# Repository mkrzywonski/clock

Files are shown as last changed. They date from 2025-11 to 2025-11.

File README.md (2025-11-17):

# Clock (Raspberry Pi LED Clock)

A Python-powered nightstand clock for Raspberry Pi Zero 2 W with an I²C LED display and a rotary navigation encoder.  
It syncs time via NTP, supports adjustable brightness, and includes an on-device menu to configure Wi-Fi, time format, timezone, and colon flash.

## ✨ Features

- Accurate time from NTP
- 4-digit HT16K33 LED display (14-segment)
- Smooth brightness control using a rotary encoder
- On-device settings menu:
  - Wi-Fi SSID selection + password entry
  - 12/24-hour mode
  - Timezone selection
  - Colon flash toggle
- Auto-start at boot via systemd
- Clean Python structure (Display class, input handlers, state machine)

## 📷 Photos
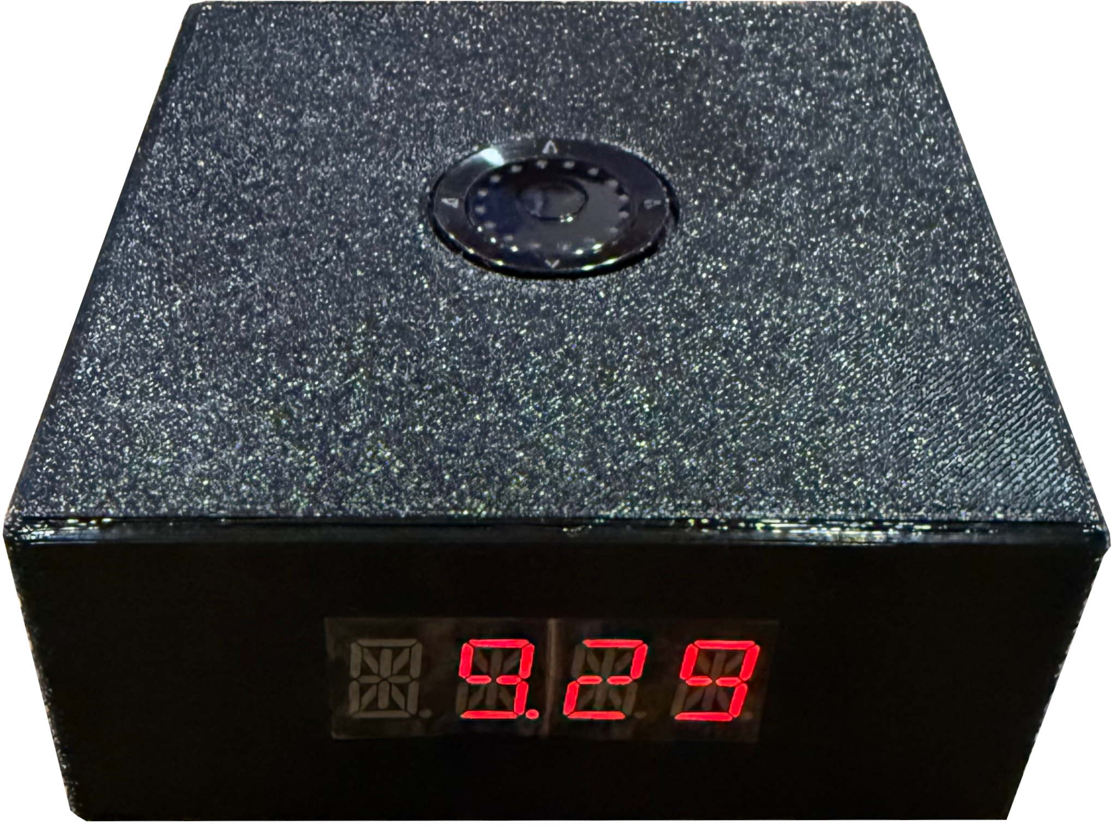
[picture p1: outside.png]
Clock exterior

Clock interior

## 🧰 Hardware

- **Raspberry Pi Zero 2 W** (other Pis likely work)
- **HT16K33 LED display** (I²C; 0x70 default address)
  https://www.amazon.com/dp/B0C1C5W7V6
- **Adafruit ANO Rotary Navigation Encoder Breakout (PID 6311)**  
  – 2 quadrature pins for rotation, 5 momentary buttons, separate commons
  https://www.adafruit.com/product/6311
- **3D Printed Case** https://www.tinkercad.com/things/d59hjFyJgNW-clock

> Power and logic are 3.3 V. Use internal pull-ups on the Pi GPIO and tie the board’s commons to **GND**.

### Example Wiring

| Encoder Pin | Purpose | Pi GPIO (BCM) | Notes |
|---|---|---|---|
| ENCA | Encoder A | GPIO17 | Input w/ internal pull-up |
| ENCB | Encoder B | GPIO18 | Input w/ internal pull-up |
| COMA | Encoder common | GND | Tie to Pi ground |
| SW1 | Button 1 (up) | GPIO27 | Input w/ internal pull-up |
| SW2 | Button 2 (down) | GPIO23 | Input w/ internal pull-up |
| SW3 | Button 3 (left) | GPIO22 | Input w/ internal pull-up |
| SW4 | Button 4 (right) | GPIO24 | Input w/ internal pull-up |
| SW5 | Button 5 (center press) | GPIO4 | Input w/ internal pull-up |
| COMB | Buttons common | GND | Tie to Pi ground |

**I²C display**

| Display Pin | Purpose | Pi Header |
|---|---|---|
| VCC | 3.3 V | 3V3 |
| GND | Ground | GND |
| SDA | I²C data | GPIO2 (SDA) |
| SCL | I²C clock | GPIO3 (SCL) |

## 🖥️ Software Requirements

- Python 3.11+ (Pi OS / Debian Bookworm/Trx)
- `smbus2` (I²C)
- `gpiozero` (inputs)  
  *(or your preferred GPIO library—adjust code accordingly)*

Optional:
- `systemd` (to run at boot)
- `timedatectl` / NTP client (for time sync)

## 🚀 Quick Start

```bash
# 1) Enable I²C (one-time)
# Add this line to /boot/firmware/config.txt and reboot:
#   dtparam=i2c_arm=on
# Then verify:
sudo apt update
sudo apt install -y i2c-tools
i2cdetect -y 1          # should show 0x70 (or your display address)

# 2) Clone the repo (use your own URL)
git clone https://github.com/<your-username>/clock.git
cd clock

# 3) Python venv
python3 -m venv venv
source venv/bin/activate
pip install -U pip
pip install -r requirements.txt  # if present; otherwise:
pip install smbus2 gpiozero

# 4) Run
python clock.py
```

If your display is on a different bus or address, adjust in the code (e.g., `bus=1`, `address=0x70`).

## 🧭 Usage & Controls

- **Default state:** Clock display (updates once per second)
- **Rotate encoder:** Adjust brightness in Clock state
  - Button press (center) → save setting
- **Button press (left/right):** Enter/cycle menu
  - **Wi-Fi SSID** → choose network
    - **Wi-Fi password** → enter using buttons/rotation
  - **12/24-hour** → toggle
  - **Timezone** → choose from curated list
  - **Colon flash** → toggle
  - **Display IP Address**

## 🧷 Systemd (run at boot)

Create `/etc/systemd/system/clock.service`:

```ini
[Unit]
Description=Pi LED Clock
After=network-online.target
Wants=network-online.target

[Service]
Type=simple
User=pi
WorkingDirectory=/home/pi/clock
ExecStart=/home/pi/clock/venv/bin/python /home/pi/clock/clock.py
Restart=on-failure
Environment=PYTHONUNBUFFERED=1

[Install]
WantedBy=multi-user.target
```

Enable it:

```bash
sudo systemctl daemon-reload
sudo systemctl enable --now clock.service
systemctl status clock.service
```

## 📶 Wi-Fi Configuration from the button pad

You probably configured Wi-Fi when you set up your Pi, but the menu can also scan SSIDs and configure credentials on-device without the need to connect a monitor and keyboard. This can be helpful if you move the clock to a location with a different Wi-Fi network.

**Instructions**
- Select WiFi from the menu and press the center button.
- The clock will scan for available networks. Use the up/down buttons to view the available SSIDs. Press the center button to select the desired SSID.
- The clock will prompt you to enter a password.
  - A single 'a' will be displayed by default
  - Use the up/down buttons or the rotary dial to select the character at the first position.
  - Use the left right arrows to change position. (e.g. select the first character of your password, then press the right arrow to move to the second character and repeat)
  - Press the center button to finish editing.
  - The clock will display the password you entered.
  - Press the left/right buttons to continue editing characters, or press the center button to accept.
  - The clock will display "GOOD" if the SSID and password were valid. The credntials will be saved.
  - The clock will display "FAIL" if the SSID and password were not vailid. Try again.
 
**Note:**
Not all typable characters can be unambiguously displayed on a 14 segment LED display. While accepting characters in the password entry routine, all four digits of the display will be used to identify the exact character being entered. The first three leftmost digits are used to indicate upper/lower case, symobols, etc. The rightmost digit will attempt to display the actual character.

For example, 1, l, i, !, |, ;, and : are all displayed the same on the 14-segment display. While entering the Wi-Fi password, '1' will be shown as "N  1" to indicate that it is a (N)umeral 1. 'l' will be displayed as "↓L l" indicating that it is a lower case L. 'i' will be displayed as "↓I i". '!' will be displayed as "↑1 !", indicating the symbol typed by pressing Shift-1 on a keyboard. And '|' will be displayed as "PIP|" indicating a pipe character. Colon and semicolon are displayed as "COL:" and "SCL;" respectively. All these characters look similar on a single 14-segment display digit. Use the 3 leftmost digits to tell these characters apart.

TLDR: The character displayed on the rightmost digit will be the closest possible 14-segment representation of the character you are entering. The Leftmost 3 digits will idicate uper/lower case or other symbols to disambiguate similarly displayed characters.

## 🧯 Troubleshooting

- **Display shows nothing**
  - `i2cdetect -y 1` should show `0x70` (or your address)
  - Check `dtparam=i2c_arm=on` and SDA/SCL wiring
- **Only some segments light**
  - Verify 14-segment mapping and that you’re writing both high/low bytes per digit
- **Encoder not responding**
  - Confirm you wired **COMA/COMB to GND** and enabled internal pull-ups on ENCA/ENCB/SW*
  - Try swapping A/B if direction feels reversed
- **Buttons double-trigger**
  - Add debounce in code (gpiozero has `bounce_time`), ensure solid ground
- **Permissions**
  - User must be in `i2c` and `gpio` groups on some setups:
    ```bash
    sudo adduser $USER i2c
    sudo adduser $USER gpio
    ```
    Log out/in.

## 🧾 License

GNU GENERAL PUBLIC LICENSE (GPLv3)

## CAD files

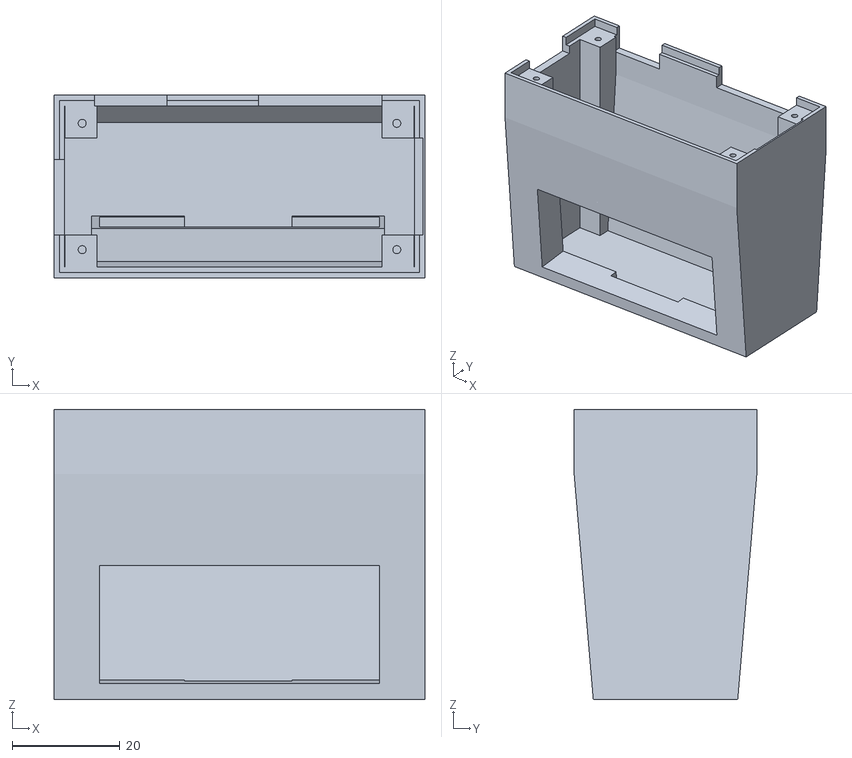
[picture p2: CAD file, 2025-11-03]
small.stl
69.0 x 34.0 x 54.0

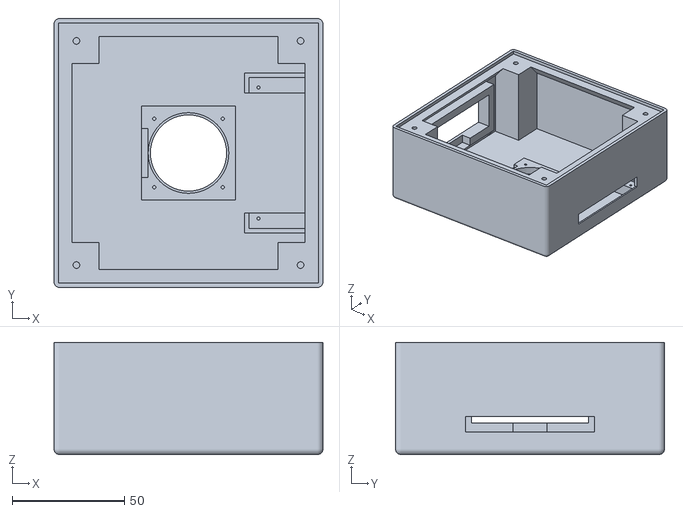
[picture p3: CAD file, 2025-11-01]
clock.stl
120.0 x 120.0 x 50.0

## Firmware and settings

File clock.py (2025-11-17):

from smbus2 import SMBus
import time
from datetime import datetime
import pytz
import sys
import select
import tty
import termios
import threading
import queue
import json
import os
from enum import Enum, auto
import subprocess
import re
from gpiozero import Device, Button, RotaryEncoder
from gpiozero.pins.pigpio import PiGPIOFactory

class ClockSettings:
    def __init__(self, filename="clock_settings.json"):
        self.filename = filename
        self.brightness = 0
        self.timezone = "America/Chicago"
        self.hour_24 = False
        self.flash_colon = True
        self.load()

    def load(self):
        if os.path.exists(self.filename):
            try:
                with open(self.filename, "r") as f:
                    data = json.load(f)
                self.brightness = data.get("brightness", 0)
                self.timezone = data.get("timezone", "America/Chicago")
                self.hour_24 = data.get("hour_24", False)
                self.flash_colon = data.get("flash_colon", True)
            except Exception as e:
                print(f"Error loading settings: {e}. Using defaults.")
                self.save()
        else:
            self.save()

    def save(self):
        data = {
            "brightness": self.brightness,
            "timezone": self.timezone,
            "hour_24": self.hour_24,
            "flash_colon": self.flash_colon
        }
        try:
            with open(self.filename, "w") as f:
                json.dump(data, f, indent=2)
        except Exception as e:
            print(f"Error saving settings: {e}")

    def increase_brightness(self):
        self.brightness += 1
        if self.brightness > 15:
            self.brightness = 15
        #self.save()

    def decrease_brightness(self):
        self.brightness -= 1
        if self.brightness < 0:
            self.brightness = 0
        #self.save()

class Display:
    # HT16K33 digit base addresses (two bytes per digit)
    _DIG_BASE = [0x00, 0x02, 0x04, 0x06]

    _SEG14 = {
        ' ':0x0000, '-':0x00C0, '[':0x0039, ']':0x000F, '_':0x0008,
        '0':0x003F, '1':0x0006, '2':0x00DB, '3':0x00CF, '4':0x00E6,
        '5':0x00ED, '6':0x00FD, '7':0x0007, '8':0x00FF, '9':0x00EF,
        '!':0x4002, '@':0x02BB, '#':0x12F8, '$':0x12ED,
        '%':0x0C24, '^':0x0120, '&':0x235D, '*':0x3FC0,
        '(':0x2400, ')':0x0900, ',':0x0800, '.':0x4000,
        '?':0x60A3, '/':0x0C00, '\\':0x2100, '~':0x0100,
        '=':0x00C8, '+':0x12C0, '{':0x0949, '}':0x2489,
        '|':0x1200, '<':0x0480, '>':0x0140, ':':0x0030,
        ';':0x0A00, '\'':0x0020, '"':0x0220, '↑':0x3800, '↓':0x0700,

        # common letters approximated on 7-seg:
        'A':0x00F7, 'a':0x00DF,
        'B':0x2479, 'b':0x00FC,
        'C':0x0039, 'c':0x00D8,
        'D':0x0930, 'd':0x00DE,
        'E':0x0079, 'e':0x00FB,
        'F':0x00F1, 'f':0x0071,
        'G':0x00BD, 'g':0x00EF,
        'H':0x00F6, 'h':0x00F4, 
        'I':0x1209, 'i':0x1200, 
        'J':0x001E, 'j':0x001E, 
        'K':0x2470, 'k':0x2470, 
        'L':0x0038, 'l':0x0018, 
        'M':0x0536, 'm':0x0536, 
        'N':0x2136, 'n':0x00D4, 
        'O':0x003F, 'o':0x00DC, 
        'P':0x00F3, 'p':0x00F3, 
        'Q':0x203F, 'q':0x20E3, 
        'R':0x20F3, 'r':0x0050, 
        'S':0x00ED, 's':0x00ED, 
        'T':0x1201, 't':0x12C0, 
        'U':0x003E, 'u':0x001C, 
        'V':0x0C30, 'v':0x0810, 
        'W':0x2836, 'w':0x2814, 
        'X':0x2D00, 'x':0x2D00, 
        'Y':0x1500, 'y':0x1500, 
        'Z':0x0C09, 'z':0x0848, 
    }

    def __init__(self, bus=1, address=0x70, brightness=0, scroll_delay=0.25, double_mid_chars=None):
        """
        :param bus: I2C bus number (your board uses bus 0)
        :param address: I2C address (default 0x70)
        :param brightness: 0..15
        :param scroll_delay: seconds between scroll steps
        :param double_mid_chars: iterable of chars that should force both middle bars (default: {'2','3','4'})
        """
        self.bus = bus
        self.address = address
        self.scroll_delay = float(scroll_delay)
        self.double_mid_chars = set(double_mid_chars or {'2', '3', '4'})
        self.colon = True  # Initialize colon state
        self._init_hw(brightness)

    # ---- Low-level helpers ----
    def _init_hw(self, brightness):
        with SMBus(self.bus) as i2c:
            # Oscillator ON
            i2c.write_byte(self.address, 0x21)
            # Display ON, blink OFF
            i2c.write_byte(self.address, 0x81)
            # Brightness (0xE0 .. 0xEF)
            i2c.write_byte(self.address, 0xE0 | (brightness & 0x0F))
            # Clear
            self.clear()

    def clear(self):
        with SMBus(self.bus) as i2c:
            i2c.write_i2c_block_data(self.address, 0x00, [0x00] * 16)

    def set_brightness(self, level):
        level = max(0, min(15, int(level)))
        with SMBus(self.bus) as i2c:
            i2c.write_byte(self.address, 0xE0 | level)

    def _encode_char_14seg(self, ch):
        """
        Return (low_byte, high_byte) for a given character.
        Uses the 14-segment value from _SEG14 and splits into two bytes.
        """
        val = self._SEG14.get(ch, 0x0000)
        low = val & 0xFF
        high = (val >> 8) & 0xFF
        return low, high

    def _write_four_chars(self, s4):
        """
        Write exactly 4 characters to the display RAM in one transaction.
        s4: length-4 string (or will be padded/truncated to 4)
        """
        s4 = (s4 + "    ")[:4]
        frame = [0x00] + [0x00] * 16
        for pos, ch in enumerate(s4):
            low, high = self._encode_char_14seg(ch)
            # Set colon bit (bit 15) in second character's high byte
            if pos == 1 and self.colon:
                high = high | 0x40  # Set bit 7 (15th bit of character) for colon
            base = self._DIG_BASE[pos]
            frame[1 + base]     = low
            frame[1 + base + 1] = high
            

        with SMBus(self.bus) as i2c:
            i2c.write_i2c_block_data(self.address, frame[0], frame[1:])

    # ---- Public API ----
    def display(self, text):
        """
        Show a string. If length <= 4: display immediately.
        If length > 4: scroll left one character at a time across 4 digits,
        then stop with the **last 4 characters** visible.
        """
        if not isinstance(text, str):
            text = str(text)

        n = len(text)
        if n <= 4:
            self._write_four_chars(text)
            return

        # Scroll window from 0..(n-4)
        for i in range(0, n - 4 + 1):
            self._write_four_chars(text[i:i+4])
            # If this is the final frame, stop without delay so it "ends" held on screen
            if i < n - 4:
                time.sleep(self.scroll_delay)

        # Final frame (last 4 chars) is already shown and remains displayed

def display_time(disp, settings):
    # Get timezone-aware current time
    tz = pytz.timezone(settings.timezone)
    now = datetime.now(tz)
    minute = now.minute
    hour = now.hour
    if not settings.hour_24:
        hour = hour % 12
        if hour == 0:
            hour = 12
    
    # Handle colon flashing
    if settings.flash_colon:
        disp.colon = (now.second % 2 == 0)
    else:
        disp.colon = True
    
    # Pad hour with space, minute with zero
    disp.display(f"{hour:2d}{minute:02d}")

def keyboard_thread_func(q):
    while True:
        ch = sys.stdin.read(1)
        if ch == '\x1b':
            seq = ch + sys.stdin.read(2)
            if seq == '\x1b[A':
                q.put("up")
            elif seq == '\x1b[B':
                q.put("down")
            elif seq == '\x1b[C':
                q.put("right")
            elif seq == '\x1b[D':
                q.put("left")
        elif ch in ('\n', '+', '-'):
            q.put(ch)

def set_flash(disp, settings, input_queue):
    while True:
        if settings.flash_colon:
            status = "On"
        else:
            status = "Off"
        disp.display(f"FLASH  {status}")
        while input_queue.empty():
            time.sleep(0.1)
        input = input_queue.get()
        if input == 'up' or input == 'down' or input == 'right' or input == 'left':
            settings.flash_colon = not settings.flash_colon
        elif input == '\n':
            settings.save()
            return

def set_24h(disp, settings, input_queue):
    while True:
        if settings.hour_24:
            status = "24"
        else:
            status = "12"
        disp.display(f"{status}")
        while input_queue.empty():
            time.sleep(0.1)
        input = input_queue.get()
        if input == 'up' or input == 'down' or input == 'right' or input == 'left':
            settings.hour_24 = not settings.hour_24
        elif input == '\n':
            settings.save()
            return

def set_timezone(disp, settings, input_queue):
    zones = {
        "Eastern": "America/New_York",
        "Central": "America/Chicago",
        "Mountain": "America/Denver",
        "Pacific": "America/Los_Angeles",
        "Alaska": "America/Anchorage",
        "Hawaii": "America/Honolulu",
        "UTC": "UTC"
    }
    index = list(zones.values()).index(settings.timezone)
    while True:
        disp.display(f"{list(zones.keys())[index]}")
        while input_queue.empty():
            time.sleep(0.1)
        input = input_queue.get()
        if input == 'up' or input == 'right':
            index = (index + 1) % len(zones)
            settings.timezone = list(zones.values())[index]
        elif input == 'down' or input == 'left':
            index = (index - 1) % len(zones)
            settings.timezone = list(zones.values())[index]
        elif input == '\n':
            settings.save()
            return

def set_wifi(disp, settings, input_queue):
    symbols = {"a": "↓A a", "b": "↓B b", "c": "↓C c", "d": "↓D d",
               "e": "↓E e", "f": "↓F f", "g": "↓G g", "h": "↓H h",
               "i": "↓I i", "j": "↓J j", "k": "↓K k", "l": "↓L l",
               "m": "↓M m", "n": "↓N n", "o": "↓O o", "p": "↓P p",
               "q": "↓Q q", "r": "↓R r", "s": "↓S s", "t": "↓T t",
               "u": "↓U u", "v": "↓V v", "w": "↓W w", "x": "↓X x",
               "y": "↓Y y", "z": "↓Z z",
               "1": "N  1", "2": "N  2", "3": "N  3", "4": "N  4",
               "5": "N  5", "6": "N  6", "7": "N  7", "8": "N  8",
               "9": "N  9", "0": "N  0",
               "A": "↑A A", "B": "↑B B", "C": "↑C C", "D": "↑D D",
               "E": "↑E E", "F": "↑F F", "G": "↑G G", "H": "↑H H",
               "I": "↑I I", "J": "↑J J", "K": "↑K K", "L": "↑L L",
               "M": "↑M M", "N": "↑N N", "O": "↑O O", "P": "↑P P",
               "Q": "↑Q Q", "R": "↑R R", "S": "↑S S", "T": "↑T T",
               "U": "↑U U", "V": "↑V V", "W": "↑W W", "X": "↑X X",
               "Y": "↑Y Y", "Z": "↑Z Z",
               "-": "   -", "_": "   _", "[": "LB [", "]": "RB ]",
               "!": "↑1 !", "@": "↑2 @", "#": "↑3 #", "$": "↑4 $",
               "%": "↑5 %", "^": "↑6 ^", "&": "↑7 &", "*": "↑8 *",
               "(": "↑9 (", ")": "↑0 )", ",": "COM,", ".": "DOT.",
               "?": "QUE?", "/": "SL /", "\\": "BSL\\", "~": "TLD~",
               "=": "EQL=", "+": "PLS+", "{": "LC {", "}": "RC }",
               "|": "PIP|", "<": "LT <", ">": "GT >", ":": "COL:", ";": "SCL;",
               "'": "SQ '", '"': 'DQ "', " ": "SPC ",
               }

    result = subprocess.run(['nmcli', '-t', '-f', 'SSID', 'device', 'wifi', 'list'], capture_output=True, text=True)
    wifi = sorted(set([line for line in result.stdout.splitlines() if line]))
    index = 0
    while True:
        disp.display(f"{wifi[index]}")
        while input_queue.empty():
            time.sleep(0.1)
        input = input_queue.get()
        if input == 'up' or input == 'right':
            index = (index + 1) % len(wifi)
        elif input == 'down' or input == 'left':
            index = (index - 1) % len(wifi)
        elif input == '\n':
            ssid = wifi[index]
            break
    
    password = []
    index = 0
    disp.display("ENTER PASSWORD")
    time.sleep(2)
    done = False

    while True:
        if index + 1 > len(password):
            letter = 0
            password.append(letter)
        else:
            # Choose index of current 
            letter = password[index]
        if not done:
            disp.display(f"{list(symbols.values())[letter]}")
        while input_queue.empty():
            time.sleep(0.1)
        input = input_queue.get()
        if input == 'up':
            password[index] = (letter + 1) % len(symbols)
            done = False
        elif input == 'down':
            password[index] = (letter - 1) % len(symbols)
            done = False
        elif input == 'right':
            index = min(index + 1, len(password))
            done = False
        elif input == 'left':
            index = max(0, index - 1)
            done = False
        elif input == '\n':
            if done:
                break    
            pw = ""
            for i in range(len(password)):
                pw += list(symbols.keys())[password[i]]
            disp.display(f"{pw}")
            done = True
    # Configure WiFi using ssid and pw
    # This will create a persistent connection profile
    try:
        add_result = subprocess.run([
            'nmcli', 'connection', 'add',
            'type', 'wifi',
            'ifname', 'wlan0',
            'con-name', ssid,
            'ssid', ssid,
            '--',
            'wifi-sec.key-mgmt', 'wpa-psk',
            'wifi-sec.psk', pw
        ], capture_output=True, text=True)
    except Exception as e:
        # nmcli not available or other execution error
        disp.display("FAIL")
        time.sleep(2)
        return

    if add_result.returncode != 0:
        # Failed to add connection profile
        disp.display("FAIL")
        time.sleep(2)
        return

    # Activate the connection and show status
    try:
        up_result = subprocess.run(['nmcli', 'connection', 'up', ssid], capture_output=True, text=True)
    except Exception:
        disp.display("FAIL")
        time.sleep(2)
        return

    if up_result.returncode == 0:
        disp.display("GOOD")
    else:
        disp.display("FAIL")
    # Give the user a moment to see the result
    time.sleep(2)

def get_wlan0_ip():
    result = subprocess.run(['ip', 'addr', 'show', 'wlan0'], capture_output=True, text=True)
    match = re.search(r'inet (\d+\.\d+\.\d+\.\d+)', result.stdout)
    if match:
        return match.group(1)
    return None

def display_ip_address(disp, settings, input_queue):
    ip = get_wlan0_ip() or "127.0.0.1"
    octet = ip.split(".")
    index = 0
    while True:
        disp.display(f"{octet[index]}")
        while input_queue.empty():
            time.sleep(0.1)
        input = input_queue.get()
        if input == 'up' or input == 'right':
            index = min(index + 1, len(octet) - 1)
        elif input == 'down' or input == 'left':
            index = max(0, index - 1)
        elif input == '\n':
            break

def poll_encoder(q):
    """
    Install gpiozero callbacks for the rotary encoder and buttons and
    post events into queue `q`.

    This uses event-driven callbacks (no active polling) for responsive
    detection. If `PIN_A`, etc. are defined in the global namespace they
    will be used, otherwise sensible defaults are chosen.
    """
    # Resolve pin numbers from globals if present (allows compatibility
    # with how pins are defined in __main__ later in this file)
    pin_a = globals().get('PIN_A', 17)
    pin_b = globals().get('PIN_B', 18)
    pin_sw = globals().get('PIN_SW', 4)
    pin_sw_up = globals().get('PIN_SW_UP', 27)
    pin_sw_down = globals().get('PIN_SW_DOWN', 23)
    pin_sw_left = globals().get('PIN_SW_LEFT', 22)
    pin_sw_right = globals().get('PIN_SW_RIGHT', 24)

    rotor = None
    btn = None
    btn_up = None
    btn_down = None
    btn_left = None
    btn_right = None
    created_factory = False

    try:
        # Ensure there's a pin factory (the main program usually sets this,
        # but be defensive here so poll_encoder can be used standalone).
        if Device.pin_factory is None:
            Device.pin_factory = PiGPIOFactory()
            created_factory = True

        # Create the rotary encoder and use the callback API for responsiveness
        # Use max_steps=0 to allow unbounded increasing/decreasing value
        rotor = RotaryEncoder(pin_a, pin_b, wrap=True)
        last = [float(rotor.value)]        

        def _on_rotated():
            try:
                current = rotor.value
                if current != last[0]:
                    q.put('up' if current > last[0] else 'down')
                    last[0] = current
            except Exception:
                # Swallow exceptions inside the callback to avoid crashing
                # the gpiozero internal thread.
                pass

        rotor.when_rotated = _on_rotated

        # Helper to create buttons that push values into the queue
        def make_btn(pin, val):
            if pin is None:
                return None
            b = Button(pin, pull_up=True, bounce_time=0.01)
            b.when_pressed = lambda: q.put(val)
            return b

        btn = make_btn(pin_sw, '\n')
        btn_up = make_btn(pin_sw_up, 'up')
        btn_down = make_btn(pin_sw_down, 'down')
        btn_left = make_btn(pin_sw_left, 'left')
        btn_right = make_btn(pin_sw_right, 'right')

        # Block the thread while callbacks do the work. Use a short sleep so
        # the thread can be responsive to interrupts but we don't busy-loop.
        while True:
            time.sleep(1)

    except Exception as e:
        # Log error so main program can continue (or fallback to keyboard)
        print(f"Encoder polling failed: {e}")
        print(f"Error type: {type(e).__name__}")
    finally:
        # Clean up devices
        try:
            if rotor:
                rotor.close()
        except Exception:
            pass
        for b in (btn, btn_up, btn_down, btn_left, btn_right):
            try:
                if b:
                    b.close()
            except Exception:
                pass
        # Only close the pin factory if we created it here
        try:
            if created_factory and Device.pin_factory:
                Device.pin_factory.close()
                Device.pin_factory = None
        except Exception:
            pass
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

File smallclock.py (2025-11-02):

from smbus2 import SMBus
import time
from datetime import datetime
import pytz
import sys
import select
import json
import os
from enum import Enum, auto
import subprocess
import re

class ClockSettings:
    def __init__(self, filename="clock_settings.json"):
        self.filename = filename
        self.brightness = 0
        self.timezone = "America/Chicago"
        self.hour_24 = False
        self.flash_colon = True
        self.load()

    def load(self):
        if os.path.exists(self.filename):
            try:
                with open(self.filename, "r") as f:
                    data = json.load(f)
                self.brightness = data.get("brightness", 0)
                self.timezone = data.get("timezone", "America/Chicago")
                self.hour_24 = data.get("hour_24", False)
                self.flash_colon = data.get("flash_colon", True)
            except Exception as e:
                print(f"Error loading settings: {e}. Using defaults.")
                self.save()
        else:
            self.save()

    def save(self):
        data = {
            "brightness": self.brightness,
            "timezone": self.timezone,
            "hour_24": self.hour_24,
            "flash_colon": self.flash_colon
        }
        try:
            with open(self.filename, "w") as f:
                json.dump(data, f, indent=2)
        except Exception as e:
            print(f"Error saving settings: {e}")

    def increase_brightness(self):
        self.brightness += 1
        if self.brightness > 15:
            self.brightness = 15
        #self.save()

    def decrease_brightness(self):
        self.brightness -= 1
        if self.brightness < 0:
            self.brightness = 0
        #self.save()

class Display:
    """
    HT16K33 4-digit 7-seg (Adafruit-style) with center colon.
    - Digits are 1 byte each.
    - Colon is controlled via RAM address 0x04 (0x02 turns it on).
    """

    # RAM addresses for each of the 4 digits (wired this way on the Adafruit backpack)
    _DIG_ADDR = [0x00, 0x02, 0x06, 0x08]
    _COLON_ADDR = 0x04  # write 0x02 to turn colon on, 0x00 to turn it off

    # 7-seg glyphs (bit layout matches the backpack’s wiring)
    # NOTE: dp (decimal point) bit is 0x80 on the same digit byte.
    _SEG7 = {
        ' ': 0x00, '-': 0x40, '_': 0x08,
        '0': 0x3F, '1': 0x06, '2': 0x5B, '3': 0x4F,
        '4': 0x66, '5': 0x6D, '6': 0x7D, '7': 0x07,
        '8': 0x7F, '9': 0x6F,

        # Letters good enough for menus (“FLASH”, “ZONE”, “WIFI”, “IP”, “24H”)
        'A': 0x77, 'a': 0x5F,
        'b': 0x7C, 'C': 0x39, 'c': 0x58,
        'd': 0x5E, 'E': 0x79, 'e': 0x7B,
        'F': 0x71, 'H': 0x76, 'h': 0x74,
        'I': 0x06, 'i': 0x04, 'J': 0x1E,
        'L': 0x38, 'n': 0x54, 'o': 0x5C,
        'P': 0x73, 'r': 0x50, 'S': 0x6D,
        't': 0x78, 'U': 0x3E, 'Y': 0x6E,
        'Z': 0x5B,  # same as '2' visually
        # You can add more as needed
    }

    def __init__(self, bus=1, address=0x70, brightness=0, scroll_delay=0.25):
        self.bus = bus
        self.address = address
        self.scroll_delay = float(scroll_delay)
        self.colon = True
        self._init_hw(brightness)

    # ---- Low-level helpers ----
    def _init_hw(self, brightness):
        from smbus2 import SMBus
        with SMBus(self.bus) as i2c:
            # Oscillator ON
            i2c.write_byte(self.address, 0x21)
            # Display ON, blink OFF
            i2c.write_byte(self.address, 0x81)
            # Brightness (0xE0..0xEF)
            i2c.write_byte(self.address, 0xE0 | (int(brightness) & 0x0F))
            self.clear()

    def clear(self):
        from smbus2 import SMBus
        with SMBus(self.bus) as i2c:
            i2c.write_i2c_block_data(self.address, 0x00, [0x00] * 16)

    def set_brightness(self, level):
        from smbus2 import SMBus
        level = max(0, min(15, int(level)))
        with SMBus(self.bus) as i2c:
            i2c.write_byte(self.address, 0xE0 | level)

    def _encode_char_7seg(self, ch):
        # Accept both ASCII and ints for convenience
        if isinstance(ch, int) and 0 <= ch <= 9:
            ch = str(ch)
        return self._SEG7.get(ch, 0x00)

    def _write_four_chars(self, s4):
        """
        Write exactly 4 characters + colon in one go.
        s4 is padded/truncated to 4.
        """
        from smbus2 import SMBus

        s4 = (s4 + "    ")[:4]
        # Build a 16-byte frame starting at 0x00
        frame = [0x00] + [0x00] * 16

        # Digits
        for pos, ch in enumerate(s4):
            glyph = self._encode_char_7seg(ch)
            addr = self._DIG_ADDR[pos]
            frame[1 + addr] = glyph

        # Colon
        frame[1 + self._COLON_ADDR] = 0x02 if self.colon else 0x00

        with SMBus(self.bus) as i2c:
            i2c.write_i2c_block_data(self.address, frame[0], frame[1:])

    # ---- Public API ----
    def display(self, text):
        """
        Show a string. If length <= 4: display immediately.
        If length > 4: scroll left across 4 digits, then leave
        the final 4 characters showing.
        """
        import time
        if not isinstance(text, str):
            text = str(text)

        n = len(text)
        if n <= 4:
            self._write_four_chars(text)
            return

        for i in range(0, n - 4 + 1):
            self._write_four_chars(text[i:i+4])
            if i < n - 4:
                time.sleep(self.scroll_delay)


def display_time(disp, settings):
    # Get timezone-aware current time
    tz = pytz.timezone(settings.timezone)
    now = datetime.now(tz)
    minute = now.minute
    hour = now.hour
    if not settings.hour_24:
        hour = hour % 12
        if hour == 0:
            hour = 12
    
    # Handle colon flashing
    if settings.flash_colon:
        disp.colon = (now.second % 2 == 0)
    else:
        disp.colon = True
    
    # Pad hour with space, minute with zero
    disp.display(f"{hour:2d}{minute:02d}")
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

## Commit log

2025-11-01 Added STL file for 3d printed case
    [clock.stl]
2025-11-01 Add link to 3D printed case in README
    Added a link to the 3D printed case for reference.
2025-11-03 STL file or smaller clock
    [small.stl]
